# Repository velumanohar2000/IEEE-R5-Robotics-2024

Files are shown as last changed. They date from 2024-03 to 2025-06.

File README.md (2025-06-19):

# Bit Bangers IEEE Region 5 Robotics Competition Robot

This repository contains all resources for the Bit Bangers team's entry in the IEEE Region 5 Robotics Competition.

## Repository Structure

- **Archives/**  
  Contains reference schematics, SolidWorks files, and other archived materials.

- **CAD/**  
  3D models and design files for robot components (STL format).

- **Docs/**  
  Documentation, datasheets, test results, and strategy notes for hardware and software components.

- **Images/**  
  Logos, board images, and other graphics.

- **Software/**  
  All firmware and code for the robot, organized as follows:
  - **Libraries/**  
    Reusable code modules and hardware drivers (e.g., motor controllers, sensors).
  - **Projects/**  
    Main project codebases, such as the robot firmware and remote control.
  - **Testing/**  
    Test programs and experiments for hardware and software validation.

## Getting Started

1. **Hardware**  
   Refer to the CAD and Docs folders for hardware designs and datasheets.

2. **Software**  
   See [Software/README.md](Software/README.md) for details on the code organization.  
   Each project and library may have its own README or documentation.

3. **Building & Running Code**  
   - Navigate to the relevant project or test directory in `Software/`.
   - Follow any provided makefiles or build instructions.

## Authors

Bit Bangers - UTA IEEE Region 5 Robotics Team  
See individual file headers for contributor information.

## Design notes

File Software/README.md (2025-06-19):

- Libraries -> stuff like motor controller libraries with header files
- Testing -> testing libraries for use in the final projects
- Projects -> the actual final projects like the robot or kill switch remote

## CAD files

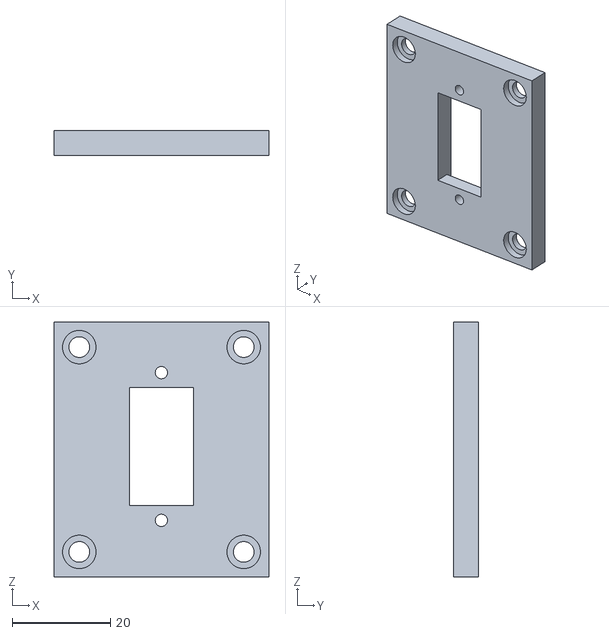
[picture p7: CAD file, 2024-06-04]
CAD/Servo_Platform.stl
43.6 x 5.00 x 51.8

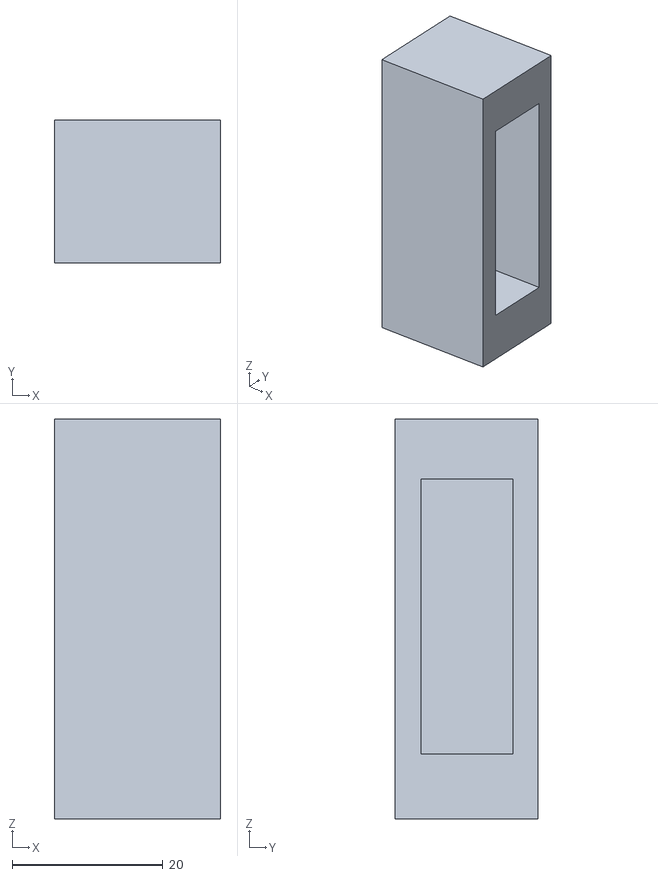
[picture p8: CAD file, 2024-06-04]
CAD/Block.stl
22.0 x 19.0 x 53.0

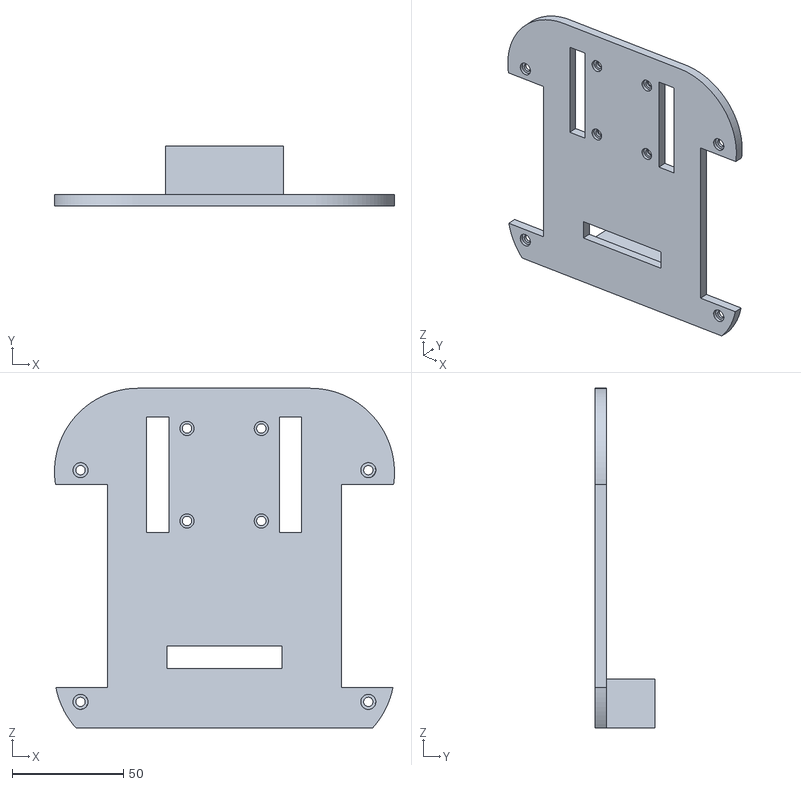
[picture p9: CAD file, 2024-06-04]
CAD/Chassis_Layer_2.stl
152.8 x 26.8 x 152.6

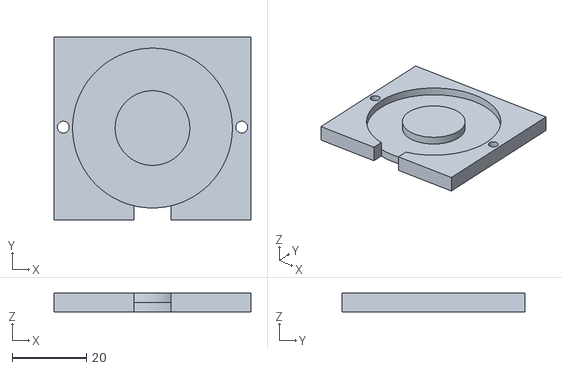
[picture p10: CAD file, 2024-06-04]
CAD/Coil_Slot.stl
53.0 x 49.3 x 5.00

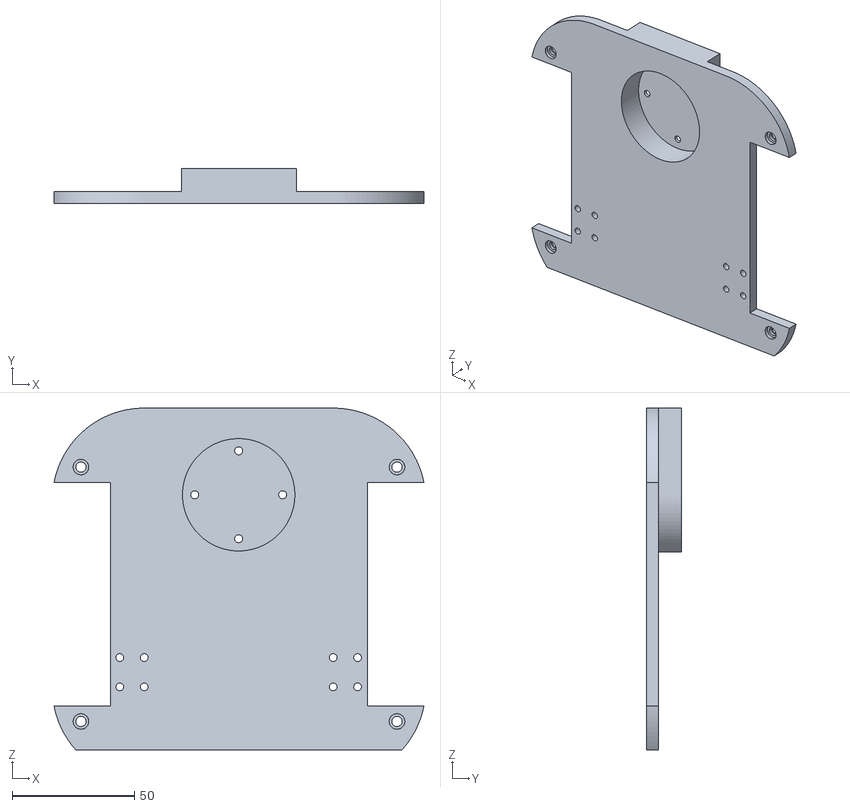
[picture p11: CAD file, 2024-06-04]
CAD/Chassis+w+Swivel+holes.stl
151.5 x 14.5 x 139.9

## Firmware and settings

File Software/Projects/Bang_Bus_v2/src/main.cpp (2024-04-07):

#include <Arduino.h>
#include <Servo.h>
#include <stdbool.h>
#include <Adafruit_BNO08x.h>
#include <Wire.h>
#include <math.h>
#include <ESP32MotorControl.h>
#include <VL53L1X_MULTIPLE.h>
#include "BNO085_heading.h"
#include "motor_control_v2.h",
#include "SparkFun_VL53L1X.h"
#include "IR_switch.h"

// Whisker
uint8_t WHISKER_STOP_DIS = 30;

#define MAX_PRELIM_DIST 60
#define MIN_WALL_DIST_CM 10
#define MAX_WALL_DIST_CM 11

#define TURN_TO_ANGLE_DIFF 2
#define DRIVE_TO_ANGLE_DIFF 20

// Sleep
#define XSHUT_PIN 18

// Variables & Constants ------------------------------------------------------

/*
  Global Variable for the Motors
*/
ESP32MotorControl motors;
// Motors
// Left
const uint8_t MOTOR_A_IN_1 = 6;
const uint8_t MOTOR_A_IN_2 = 7;
int16_t A_LEFT_MOTOR_OFFSET = 15;

// RIGHT MOTOR
const uint8_t MOTOR_B_IN_3 = 5;
const uint8_t MOTOR_B_IN_4 = 4;
int16_t B_RIGHT_MOTOR_OFFSET = 15;

/*
  Global Variable for IMU
*/
Adafruit_BNO08x bno08x;
sh2_SensorValue_t sensorValue;
float offsetForImu = 0;
float goal = 85;

/*
  Globals for (VL53L1X) Whisker
*/
SFEVL53L1X lrf1_init;
SFEVL53L1X lrf2_init;

float frontVLcm = 1000;
float sideVLcm;
// int frontVLcm = 1000;                            // whisker
float frontVLcmInch = 1000; // whisker
int whiskOffset = 0;
bool wallFound = false;

/*
  globals for servo
*/
Servo myservo = Servo();
uint8_t servoPin = 2;
uint16_t servoPosition = 90;

/*
  Globals for IR sensor & sleep
*/
const uint32_t lit_code = 0x574309F6;     // Amazon button
const uint32_t unalive_code = 0x5743D32C; // Netflix button
gpio_num_t ir_pin = GPIO_NUM_11;          // pin number of IR receiver(s)

void setup()
{
  Serial.begin(115200);

  setupBNO085(&bno08x); // Initialize the IMU
  // pinMode(XSHUT_PIN, OUTPUT);
  // digitalWrite(XSHUT_PIN, 0);

  initIR(lit_code, unalive_code);
  while (!wokeFromIR())
  {
    timeToSleep();
  }
  // digitalWrite(XSHUT_PIN, 1);

  delay(1000);

  delay(10);
  Serial.println("*****BANGING THE BUS******\n\n");
  delay(500);

  Wire.begin(9, 8); // init Wire
  init_2_VL53L1X(); // init periscopes

  motors.attachMotors(MOTOR_B_IN_3, MOTOR_B_IN_4, MOTOR_A_IN_1, MOTOR_A_IN_2); // init motors

  uint8_t i = 0;
  offsetForImu = getCurrentAngle();

  Serial.println("offset: ");
  Serial.println(offsetForImu);

  float currentAngle = getCurrentAngle();

  Serial.print("Current Angle: ");
  Serial.println(currentAngle);

  delay(500);

  for (i = 0; i < 50; i++)
  {
    float test = getLrfDistanceCm(1);
    test = getLrfDistanceCm(2);
    Serial.printf("LRF1: %f\n", test);
  }
  myservo.write(servoPin, 90);
  delay(500);
}

void sleepHandler()
{
  stopMotors();
  Wire.end();
  digitalWrite(XSHUT_PIN, 0);
  delay(100);
}

void checkSleep()
{
  if (sleepCodeReceived())
  {
    sleepHandler();
    timeToSleep();
    ESP.restart();
  }
}

// void driveToHeading(float goalHeading)
// {
//   float currentAngle = -1;
//   float absVal;
//   float angleDiff;
//   unsigned long currentMillis;
//   unsigned long previousMillis = 0;
//   uint32_t interval = 1000;
//   uint16_t i = 0;

//   // bool goToHeading = true;
//   // while (goToHeading)
//   // {
//   currentAngle = getCurrentAngle();

//   angleDiff = goalHeading - currentAngle;
//   absVal = abs(angleDiff);
//   uint32_t turnDiff = DRIVE_TO_ANGLE_DIFF;
//   // Serial.println(absVal);
//   if (absVal > (360 - turnDiff))
//   {
//     absVal = 359.99 - absVal;
//     angleDiff = 359.99 - angleDiff;
//   }
//   Serial.println(angleDiff);
//   Serial.println(absVal);
//   Serial.println();

//   if (absVal > turnDiff)
//   {
//     // stopMotors();
//     // delay(20);
//     turnToHeading(goalHeading-10, 60);
//   }
//   else if (absVal <= 15 && absVal >= 5)
//   {
//     if ((angleDiff >= 0) && (absVal <= 180))
//     {
//       turn2(COUNTER_CLOCKWISE, 65, 30);
//     }
//     else if ((angleDiff < 0) && (absVal <= 180))
//     {
//       turn2(CLOCKWISE, 65, 30);
//     }
//     else if ((angleDiff >= 0) && (absVal >= 180))
//     {
//       turn2(CLOCKWISE, 65, 30);
//     }
//     else
//     {
//       turn2(COUNTER_CLOCKWISE, 65, 30);
//     }
//     previousMillis = currentMillis = millis();
//   }
//   else if (absVal < 5 && absVal >= 2)
//   {
//     if ((angleDiff >= 0) && (absVal <= 180))
//     {
//       turn2(COUNTER_CLOCKWISE, 65, 10);
//     }
//     else if ((angleDiff < 0) && (absVal <= 180))
//     {
//       turn2(CLOCKWISE, 65, 10);
//     }
//     else if ((angleDiff >= 0) && (absVal >= 180))
//     {
//       turn2(CLOCKWISE, 65, 10);
//     }
//     else
//     {
//       turn2(COUNTER_CLOCKWISE, 65, 10);
//     }
//   }
//   else
//   {
//     move(FORWARD, 65);
//   }
//   // }
// }

void turnToHeading(float goal, uint8_t speed)
{
  stopMotors();
  // speed = 60;
  printf("Goal: %f\n", goal);
  // delay(3000);
  float absVal;
  float angleDiff;
  uint8_t i = 0;

  float currentAngle = getCurrentAngle();

  // printToLcd("Current Angle: ", currentAngle);
  angleDiff = goal - currentAngle;
  absVal = abs(angleDiff);
  uint32_t turnDiff = TURN_TO_ANGLE_DIFF;
  // Serial.println(absVal);
  if (absVal > 360 - turnDiff)
  {
    absVal = 359.99 - absVal;
    angleDiff = 359.99 - angleDiff;
  }
  // Serial.println(angleDiff);
  // Serial.println(absVal);
  // Serial.println();

  while (absVal > turnDiff)
  {
    checkSleep();
    if ((angleDiff >= 0) && (absVal <= 180))
    {
      // Serial.print(" case 1: ");
      turn(COUNTER_CLOCKWISE, speed);
    }
    else if ((angleDiff < 0) && (absVal <= 180))
    {
      // Serial.print(" case 2: ");
      turn(CLOCKWISE, speed);
    }
    else if ((angleDiff >= 0) && (absVal >= 180))
    {
      // Serial.print(" case 3: ");
      turn(CLOCKWISE, speed);
    }
    else
    {
      // Serial.print(" case 4: ");
      turn(COUNTER_CLOCKWISE, speed);
    }

    currentAngle = getCurrentAngle();

    // Serial.println(goal);
    angleDiff = goal - currentAngle;
    absVal = abs(angleDiff);
    if (absVal > (360 - TURN_TO_ANGLE_DIFF)) // was (absVal > 360 - turnDiff)
    {
      absVal = 359.99 - absVal;
      angleDiff = 359.99 - angleDiff;
    }
    // Serial.println(angleDiff);
    // Serial.println(absVal);
    // Serial.println();
  }
  stopMotors();
}
void driveToHeading(float goalHeading)
{
  float currentAngle = -1;
  float absVal;
  float angleDiff;
  unsigned long currentMillis;
  unsigned long previousMillis = 0;
  uint32_t interval = 1000;
  uint16_t i = 0;

  // bool goToHeading = true;
  // while (goToHeading)
  // {
  currentAngle = getCurrentAngle();

  angleDiff = goalHeading - currentAngle;
  absVal = abs(angleDiff);
  uint32_t turnDiff = DRIVE_TO_ANGLE_DIFF;
  // Serial.println(absVal);
  if (absVal > (360 - turnDiff))
  {
    absVal = 359.99 - absVal;
    angleDiff = 359.99 - angleDiff;
  }
  Serial.println(angleDiff);
  Serial.println(absVal);
  Serial.println();

  if (absVal > turnDiff)
  {
    // stopMotors();
    // delay(20);
    turnToHeading(goalHeading, 60);
  }
  else if (absVal <= 15 && absVal >= 5)
  {
    if ((angleDiff >= 0) && (absVal <= 180))
    {
      turn2(COUNTER_CLOCKWISE, 65, 30);
    }
    else if ((angleDiff < 0) && (absVal <= 180))
    {
      turn2(CLOCKWISE, 65, 30);
    }
    else if ((angleDiff >= 0) && (absVal >= 180))
    {
      turn2(CLOCKWISE, 65, 30);
    }
    else
    {
      turn2(COUNTER_CLOCKWISE, 65, 30);
    }
    previousMillis = currentMillis = millis();
  }
  else if (absVal < 5 && absVal >= 2)
  {
    if ((angleDiff >= 0) && (absVal <= 180))
    {
      turn2(COUNTER_CLOCKWISE, 65, 10);
    }
    else if ((angleDiff < 0) && (absVal <= 180))
    {
      turn2(CLOCKWISE, 65, 10);
    }
    else if ((angleDiff >= 0) && (absVal >= 180))
    {
      turn2(CLOCKWISE, 65, 10);
    }
    else
    {
      turn2(COUNTER_CLOCKWISE, 65, 10);
    }
  }
  else
  {
    move(FORWARD, 65);
  }
  // }
}

// void driveToHeadingVl(float goalHeading)
// {
//   float currentReading = -1;
//   float absVal;
//   float posDiff;
//   unsigned long currentMillis;
//   unsigned long previousMillis = 0;
//   uint32_t interval = 1000;
//   uint16_t i = 0;

//   // bool goToHeading = true;
//   // while (goToHeading)
//   // {
//   currentReading = getLrfDistanceCm(2);

//   posDiff = 13 - currentReading;
//   absVal = abs(posDiff);
//   // uint32_t turnDiff = DRIVE_TO_ANGLE_DIFF;
//   // // Serial.println(absVal);
//   // if (absVal > (360 - turnDiff))
//   // {
//   //   absVal = 359.99 - absVal;
//   //   angleDiff = 359.99 - angleDiff;
//   // }
//   Serial.println(posDiff);
//   Serial.println(absVal);
//   Serial.println();

//   if (absVal > 20)
//   {
//     // stopMotors();
//     // delay(20);
//     turnToHeading(goalHeading, 60);
//   }
//   else if (absVal <= 15 && absVal >= 5)
//   {
//     if ((angleDiff >= 0))
//     {
//       turn2(COUNTER_CLOCKWISE, 65, 30);
//     }
//     else if ((angleDiff < 0) && (absVal <= 180))
//     {
//       turn2(CLOCKWISE, 65, 30);
//     }
//     else if ((angleDiff >= 0) && (absVal >= 180))
//     {
//       turn2(CLOCKWISE, 65, 30);
//     }
//     else
//     {
//       turn2(COUNTER_CLOCKWISE, 65, 30);
//     }
//     previousMillis = currentMillis = millis();
//   }
//   else if (absVal < 5 && absVal >= 2)
//   {
//     if ((angleDiff >= 0) && (absVal <= 180))
//     {
//       turn2(COUNTER_CLOCKWISE, 65, 10);
//     }
//     else if ((angleDiff < 0) && (absVal <= 180))
//     {
//       turn2(CLOCKWISE, 65, 10);
//     }
//     else if ((angleDiff >= 0) && (absVal >= 180))
//     {
//       turn2(CLOCKWISE, 65, 10);
//     }
//     else
//     {
//       turn2(COUNTER_CLOCKWISE, 65, 10);
//     }
//   }
//   else
//   {
//     move(FORWARD, 65);
//   }
//   // }
// }

unsigned long currentMillis = 0;
unsigned long previousMillis = 0;
bool runMillis = 1;
uint32_t interval = 1000;
uint16_t states = 0;

bool firstButton = true;
bool firstRun = true;
#define INITIAL 0
#define RIDE_RIGHT_WALL 1
#define TURN_90_DEG 2
#define TURN_TO_BUTTON 3
#define HIT_BUTTON 4
#define MOVE_BACKWARDS 5
#define TURN_90_DEGREE_AGAIN 6
#define TURN_OTHER_WAY 7
#define STOP 8

void jiggleForRound1()
{
  uint16_t position = 0;
  float currentAngle = getCurrentAngle();
  if (currentAngle >= 0 && currentAngle <= 90)
  {
    position = (90 - currentAngle);
  }
  else if (currentAngle >= 270)
  {
    position = ((360 - currentAngle) + 90);
  }
  else if (currentAngle >= 180 && currentAngle <= 270)
  {
    position = (90 - (currentAngle - 180));
  }
  else if (currentAngle < 180 && currentAngle >= 90)
  {
    position = (180 - currentAngle + 90);
  }
  myservo.write(servoPin, position);
}

uint16_t speed;
unsigned long currentMillisLoop;
unsigned long previousMillisLoop;
;
uint16_t intervalMillisLoop = 7000;

void loop()
{
  checkSleep();
  // if (getLrfDistanceCm(2) >= 25)
  // {
  //   turnToHeading(270, 60);
  //   currentMillis = millis();
  //   previousMillis = millis();
  //   while (currentMillis - previousMillis <= 2000)
  //   {
  //     printf("Current Angle: %f\n", getCurrentAngle());
  //     currentMillis = millis();
  //   }
  //   // turnToHeading(270, 60);

  //   //  delay(3000);
  //   while (getLrfDistanceCm(1) >= 20)
  //   {
  //     driveToHeading(270);
  //   }
  // }

  // stopMotors();
  // delay(2000);
  // turnToHeading(0, 60);
  // stopMotors();
  float check = getLrfDistanceCm(2);
  switch (states)
  {
  case INITIAL:
  {
    Serial.printf("LRF 2: %f\n", check);
    if (check >= 19.0)
    {
      Serial.printf("here\n");
      turnToHeading(270, 70);
      currentMillis = millis();
      previousMillis = millis();
      while (currentMillis - previousMillis <= 2000)
      {
        printf("Current Angle: %f\n", getCurrentAngle());
        currentMillis = millis();
      }
      // turnToHeading(270, 60);

      //  delay(3000);
      while (getLrfDistanceCm(1) >= 15)
      {
        Serial.printf("in the while\n");
        driveToHeading(270);
      }
    }
    stopMotors();
    delay(500);
    turnToHeading(355, 70);
    stopMotors();
    delay(500);
    states = RIDE_RIGHT_WALL;
    break;
  }
  case RIDE_RIGHT_WALL:
  {
    jiggleForRound1();
    currentMillisLoop = millis();
    if (runMillis == 1)
    {
      previousMillisLoop = millis();
      runMillis = 0;
    }
    if (currentMillisLoop - previousMillisLoop >= intervalMillisLoop)
    {
      frontVLcm = getLrfDistanceCm(1);
    }
    else
    {
      frontVLcm = 50;
    }
    //frontVLcm = getLrfDistanceCm(1);
    // frontVLcm = getLrfDistanceCm(1)
    // currentAngle = getHeading();
    if(!firstButton){
      WHISKER_STOP_DIS = 25;
    }
    if (frontVLcm > (WHISKER_STOP_DIS))
    {
      if (frontVLcm > 1200)
        speed = 255;
      else if (frontVLcm > 300)
        speed = 80;
      else
        speed = 50;
      sideVLcm = getLrfDistanceCm(2);

      Serial.printf("ult dist %f: \n", sideVLcm);
      if (sideVLcm > MAX_PRELIM_DIST)
      {
        stopMotors();
      }
      else if (sideVLcm > MAX_WALL_DIST_CM)
      {
        turn(CLOCKWISE, speed);
        delay(40);
        move(FORWARD, speed);
        delay(40);
      }
      else if (sideVLcm < MIN_WALL_DIST_CM)
      {
        turn(COUNTER_CLOCKWISE, speed);
        delay(40);
        move(FORWARD, speed);
        delay(40);
      }
      else
        move(FORWARD, speed);
    }
    else
    {
      stopMotors();
      states = TURN_90_DEG;
      // currentAngle = getHeading();
    }
    break;
  }
  case TURN_90_DEG:
  {
    float angle = 90;
    if (!firstButton)
    {
      turnToHeading(270, 70);
      stopMotors();
      delay(500);
      angle = 270.0;
    }
    else
    {
      turnToHeading(90, 70);
      stopMotors();
      delay(500);
    }
    myservo.write(servoPin, 90);
    if (getLrfDistanceCm(1) > 35)
    {
      while (getLrfDistanceCm(1) < 30)
      {
        driveToHeading(angle);
      }
    }
    states = TURN_TO_BUTTON;
    break;
  }
  case TURN_TO_BUTTON:
  {
    if (!firstButton)
    {
      turnToHeading(180, 70);
      stopMotors();
      delay(500);
    }
    else
    {
      turnToHeading(0, 70);
      stopMotors();
      delay(500);
    }
    states = HIT_BUTTON;
    break;
  }
  case HIT_BUTTON:
  {
    move(FORWARD, 240);
    delay(300);
    stopMotors();
    delay(500);
    states = MOVE_BACKWARDS;
    break;
  }
  case MOVE_BACKWARDS:
  {
    move(BACKWARD, 240);
    delay(500);
    stopMotors();
    delay(500);
    if (!firstButton)
    {
      states = STOP;
    }
    else
    {
      states = TURN_90_DEGREE_AGAIN;
    }
    break;
  }
  case TURN_90_DEGREE_AGAIN:
  {
    turnToHeading(90, 70);
    stopMotors();
    delay(500);
    while (getLrfDistanceCm(1) > 17)
    {
      driveToHeading(90);
    }

    states = TURN_OTHER_WAY;
    break;
  }
  case TURN_OTHER_WAY:
  {
    turnToHeading(180, 70);
    stopMotors();
    delay(500);
    if (firstButton)
    {
      states = RIDE_RIGHT_WALL;
      firstButton = false;
      runMillis = 1;
    }
    else
    {
      states = STOP;
    }
    break;
  }
  case STOP:
  {
    while (1)
    {
      void checkSleep();
      currentMillis = millis();
      jiggleForRound1();
      if (currentMillis - previousMillis >= interval)
      {
        printf("LRF 1 (cm): %f\tLRF 2 (cm): %f\n", getLrfDistanceCm(1), getLrfDistanceCm(2));
        printf("Current Angle: %f\n", getCurrentAngle());
        previousMillis = millis();
      }
    }
  }
  }
  // driveToHeading(0);
}

// int16_t findCardinalheading()
// {
//   float currentAngle = getCurrentAngle();
//   if (currentAngle >= 0 && currentAngle < 45 || currentAngle >= 315)
//   {
//     return 0; // North
//   }
//   else if (currentAngle >= 45 && currentAngle < 135)
//   {
//     return 90; // East
//   }
//   else if (currentAngle >= 135 && currentAngle < 225)
//   {
//     return 180; // South
//   }
//   else if (currentAngle >= 225 && currentAngle < 315)
//   {
//     return 270; // West
//   }
//   else
//   {
//     return -1; // Error
//   }
// }

// void jiggle()
// {
//   float lrf1;
//   float lrf2;
//   float currentHeading = getCurrentAngle();
//   uint16_t cardinalHeading = findCardinalheading();
//   float servoPosition = cardinalHeading - currentHeading; // Calculate the difference between the cardinal heading and the current heading
//   if (abs(servoPosition) > 90)
//   {
//     servoPosition = 359.99 - abs(servoPosition); // 359.99 is the max value for the servo
//   }

//   servoPosition += 90;                    // Add 90 because 90 degress is the middle position for the servo (therefore it is the current heading of the car)
//   myservo.write(servoPin, servoPosition); // tell servo to go to position in variable 'pos'
//   delay(15);                              // waits 15ms for the servo to reach the position
//   lrf1 = getLrfDistanceCm(1);
//   lrf2 = getLrfDistanceCm(2);
//   // Serial.print("LRF1: ");
//   // Serial.print(lrf1);
//   // Serial.print("\tLRF2: ");
//   // Serial.println(lrf2);
//   // findPosition(cardinalHeading, lrf1, lrf2); // Find the position of the car
// }

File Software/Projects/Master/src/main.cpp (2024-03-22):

/*
 * Bit Bangers Master Robot
 * github.com/Bit-Bangers-UTA/Senior-Design
*/

// Libraries ------------------------------------------------------------------

#include "Arduino.h"
#include <stdbool.h>
#include <ESP32Servo.h>
#include "lrf.h"
#include "Wire.h"
#include "map.h"
#include "motor_control.h"
#include "VL53L1X.h"
#include "Ultrasonic.h"
#include <Adafruit_BNO08x.h>
#include "math.h"
#include "BNO085_heading_acceleration.h"
// #include "SafeString.h"
#include "millisDelay.h"

// Defines --------------------------------------------------------------------

// Modes

// Preprocessor Directives
// #define PRELIMS
// #define PRELIMS_DRAFT
// #define PRELIMS_DRAFT_V2
// #define CHECK_I2C
// #define VELU
// #define TURNS
// #define TURNS_2
// #define TURNS_3
#define TURNS_4
// #define INTERRUPTS_CHECK

// Motors
#define MOTORA_IN_1 39
#define MOTORA_IN_2 40
#define MOTORB_IN_3 6
#define MOTORB_IN_4 7

//IMU
#define IMU_INTERRUPT 10

// Whisker
#define WHISKER_STOP_DIS 8
#define MAX_PRELIM_DIST 60

// LRF
#define LRF_ADDRESS_1 0x10
#define LRF_ADDRESS_2 0x20

// Variables & Constants ------------------------------------------------------

/*
counter = 1
++
360 * counter
*/

// Servo
int pos = 0; // variable to store the servo position
// Recommended PWM GPIO pins on the ESP32 include 2,4,12-19,21-23,25-27,32-33
int servoPin = 2;

// Map
// create map and buffer
struct Coordinate *local_maxes[4];
int local_max_index = 0;

// Ultrasonic Sensor
int ultraDistance = 100;         // ultrasonic
float ultraDistanceInch;           // ultrasonic

// Whisker
int whiskDistance;                           // whisker
float whiskDistanceInch = 1000;            // whisker
bool wallFound = false;

// IMU
float test = 45.0;
float nextAngle = 90.0;
uint16_t speed = 128;
// #define TIRE_DELAY 100
// millisDelay tireDelay;
// float angleDiff = 0;
// float startingangle = 0;
uint32_t m = 0;
// Structures & Classes -------------------------------------------------------

// Servo
Servo myservo; // create servo object to control a servo
SFEVL53L1X distanceSensor;
float dt = 0;
float millisOld = 0;
unsigned long lastTime, currentTime = 0;
float x, y, z = 0;
float thetaZ = 0;
// float angle = 0;
uint32_t timeDifference = 0;

// 16 servo objects can be created on the ESP32

// Ultrasonic Sensor
Ultrasonic ultrasonic(0, 1);

// IMU
Adafruit_BNO08x bno08x;
sh2_SensorValue_t sensorValue;

// Functions ------------------------------------------------------------------
// void IRAM_ATTR imuIsr() {
//   // newDataFlag = true;
//   Serial.println("triggered");
//   if (bno08x.getSensorEvent(&sensorValue))
//   {
//     switch (sensorValue.sensorId)
//     {
//       case SH2_GYROSCOPE_CALIBRATED:
//       {
//         z = sensorValue.un.gyroscope.z;
//         break;
//       }
//       default:
//         break;
//     }
//   currentTime = micros();
//   dt = (currentTime - lastTime - 0)/1000000.0;
//   lastTime = currentTime;
//   thetaZ += z*dt;
//   angle = thetaZ*(180/M_PI);
//   if(angle > 360)
//     angle -= 360;
//   else if(angle < 0)
//     angle += 360;
//   }
// }

float getHeading()
{

  float angle = 0;
  float retVal = -1;
  float z = 0;
  if (bno08x.getSensorEvent(&sensorValue))
  {
    retVal = calculateHeading(sensorValue.un.arvrStabilizedRV.i, sensorValue.un.arvrStabilizedRV.j, sensorValue.un.arvrStabilizedRV.k, sensorValue.un.arvrStabilizedRV.real);
  
  // if (bno08x.getSensorEvent(&sensorValue))
  // {
  //   switch (sensorValue.sensorId)
  //   {
  //     case SH2_GYROSCOPE_CALIBRATED:
  //     {
  //       z = sensorValue.un.gyroscope.z;
  //       break;
  //     }
  //     default:
  //       break;
  //   }
  

  // Serial.print(angle);
  // if(angle >= 359)
  //   angle -= 359;
  // else if(angle < 0)
  //   angle += 359;
  // Serial.printf("\t");
  // Serial.println(angle);
  // // if(angle == 0);
  //   // angle = 359;
  // retVal = angle;
  }
  return retVal;

}

void turnToGoalHeading(float goal)
{
  float currentAngle = -1;
  if(goal == 0)
    goal = 359;
  int32_t counter = 0;
  int32_t speed = 100;
  while(currentAngle == -1)
    currentAngle = getHeading();
  float absVal = 0;
  float angleDiff = goal - currentAngle;
  absVal = abs(angleDiff);

  while(absVal > 8)
  {
    Serial.print("abs: ");
    Serial.print(absVal);
    Serial.print(" angle: ");
    Serial.print(currentAngle);

    if((angleDiff >= 0) && (absVal <= 180))
    {
      Serial.print(" case 1: ");
      // Serial.printf("Speed = %f\n", speed + (-1 * counter));
      turn(LEFT, speed);
    }
    else if((angleDiff < 0) && (absVal <= 180))
    {
      Serial.print(" case 2: ");
      // Serial.printf("Speed = %f\n", speed + (-1 * counter));
      turn(RIGHT, speed);
    }
    else if((angleDiff >= 0) && (absVal >= 180))
    {
      Serial.print(" case 3: ");
      // Serial.printf("Speed = %f\n", speed + (-1 * counter));
      turn(RIGHT, speed);
    }
    else
    {
      Serial.print(" case 4: ");
      // Serial.printf("Speed = %f\n", speed + (-1 * counter));
      turn(LEFT, speed);
    }
    counter++;
    if(counter > 12)
      counter = 5;
    currentAngle = getHeading();
    // if(currentAngle > 360)
    //   currentAngle -= 360;
    // if(currentAngle < 0)
    //   currentAngle += 360;
    Serial.println(goal);
    absVal = 0;
    angleDiff = goal - currentAngle;
    absVal = abs(angleDiff);
  }

}

void getWhiskerDistance()
{
  distanceSensor.startRanging(); //Write configuration bytes to initiate measurement
  while (!distanceSensor.checkForDataReady())
  {
    delay(1);
  }
  whiskDistance = distanceSensor.getDistance(); //Get the result of the measurement from the sensor
  distanceSensor.clearInterrupt();
  distanceSensor.stopRanging();
  whiskDistanceInch = whiskDistance * 0.0393701;
  // Serial.printf("Whisker dis (in): %f\n", whiskDistanceInch);
}

void setup()
{
  Serial.begin(115200);
  Wire.begin(9, 8);
  // pinMode(IMU_INTERRUPT, INPUT);
  // attachInterrupt(digitalPinToInterrupt(IMU_INTERRUPT), imuIsr, FALLING);
  Serial.println("Adafruit BNO08x test!");
  // Wire.begin(9, 8);
  initMotors(MOTORA_IN_1, MOTORA_IN_2, MOTORB_IN_3, MOTORB_IN_4);
  initVL53L1X();
  setupBNO085(&bno08x);
  // northEstablished = false;
  #ifdef VELU
  // Serial.begin(115200);
  // Wire.begin(9,8);
  // Allow allocation of all timers
  ESP32PWM::allocateTimer(0);
  ESP32PWM::allocateTimer(1);
  ESP32PWM::allocateTimer(2);
  ESP32PWM::allocateTimer(3);
  myservo.setPeriodHertz(50);          // standard 50 hz servo
  myservo.attach(servoPin, 500, 2400); // attaches the servo on pin 18 to the servo object
                                       // using default min/max of 1000us and 2000us
                                       // different servos may require different min/max settings
                                       // for an accurate 0 to 180 sweep
  #endif
}
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

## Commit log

2024-03-04 Added xbox controller demo. Doesn't work with the ELEGOO smart shield, but should in the future.
    [main.cpp]
2024-03-04 feat:filter bad data
2024-03-07 Added initial code for dummy robot. Currently does not work.
    [main.cpp]
2024-03-07 Fixed bug not allowing car to reverse
    [main.cpp]
2024-03-07 added motor control project
2024-03-07 Added actual variables for forward and reversal, however code still doesn't work. Will be checked later
    [main.cpp]
2024-03-07 Added power pinouts
2024-03-07 not working front lidar code
    [main.cpp]
2024-03-07 added vl53- i2c project
2024-03-07 Remove unused function and initialize VL53L4CX sensor
2024-03-08 Added functions and addresses for i2c operation. We might be cooked, they have no documentation for user operation. We may need to use their library
2024-03-11 Added both kill switch receiver and transmitter projects
2024-03-11 Fixed formatting of various files
    [main.cpp]
2024-03-11 peak detection and imu testing
2024-03-11 add half speed ifdef for motor_control
2024-03-13 Add board_build.f_cpu and preprocessor directives, fix turning function
    [main.cpp]
2024-03-13 Added controlled capacitor testing project
2024-03-16 added test code for sevo + whiskers (not working)
    [main.cpp]
2024-03-16 mainly added comments + new code in motor control to turn with angle
2024-03-16 Change stop() with vlk from digital to pwm version
2024-03-16 Re-write motor_control to use PWM, change stop() function in main
2024-03-16 Organize map.cpp, add max distance for ultrasonic sensor
2024-03-16 Update ultrasonic sensor variable names and logic
2024-03-17 Detecting loaction with servo, it can either detect with two peaks or 1 max and 1 peak.
2024-03-17 noted some ideas on how to fix tthe diagonal location problem
    [main.cpp]
2024-03-18 removd duplicate serial and wire inits
2024-03-18 corrected draft code for first round with imu angles
    [main.cpp]
2024-03-19 bunch of broken code in master
    [main.cpp]
2024-03-20 slightyly better but still very broken master code
    [main.cpp]
2024-03-20 improved filtering for 180 degree servo
2024-03-22 included inis for s3, still broken code
    [MOTOR_CONTROL.cpp, main.cpp]
2024-03-22 made minor changes to motor control library
2024-03-22 Add RGB LED sensor project (not working)
    [main.cpp]
2024-03-22 changed the 2nd i2c bus
2024-03-22 color sensor work/ rgb no worl
2024-03-23 Revert i2c change
2024-03-23 Remove Wire1 code, change motor numbers and variable names, add ultrasonic defines
2024-03-24 Added test wee-woo program that shows usage of the RGB LED and testing upload, debug, and monitor of code with the esp-prog
2024-03-24 move Dummy_Robot, Master-Old, and old esp-now switch from /Projects to /Testing folder
2024-03-24 Move IR Kill Switch transmitter project from /Testing to /Projects
2024-03-24 Added RGB output to builtin RGB LED of c3. Needs additional filtering
2024-03-24 Adjusted BNO heading library and changed Bang Bus pins for motors
2024-03-24 motor calibration and code to drive to desired heading
2024-03-24 Add motor_control_v2 to /Libraries
2024-03-25 print to lcd
2024-03-25 added sample code for VL53L5CX
2024-03-25 initial libraries for calibration
2024-03-25 moved initial calibration code to libraries folder
2024-03-28 Added prelim code testing with OPT Whisker sensor
2024-03-30 Fixed getNextAngle(), moved code from libs back to main, edited motor offsets
    [main.cpp]
2024-03-30 changed name of IMU library because we are not getting the acceleration anymore, and moved the IMU to Wire1
2024-04-01 Added some starter code for deep sleep, but doesn't work for C3. C3 does not have EXT0 wakeup
    [main.cpp]
2024-04-01 Added deep sleep test for the ESP32-S3
2024-04-02 added code for testing just motors
2024-04-02 Add alternating direction for motor movement
2024-04-02 Update motor pin assignments
2024-04-02 add sensor color pages
2024-04-03 Fix pin assignments for LRF shutdown pins
2024-04-03 Update color detection to print colors to serial
2024-04-03 Update print statement in main.cpp
2024-04-03 Turned color detection into library, added small library test for sensor
2024-04-03 fixed stoppin issue unable to fix the smooth travel issue
    [main.cpp]
2024-04-03 changed the name for the sensor
2024-04-03 Add new libraries (ESP32Servo and ESP32S2 AnalogWrite) to bangbus
2024-04-03 Update motor control offsets
2024-04-03 Fix motor stop bug in turn function
2024-04-03 Update whisker and wall distance constants (broken ass code)
    [main.cpp]
2024-04-03 Fix IR sleep integration code. It now works pog
    [main.cpp]
2024-04-03 Tune color sensor
2024-04-04 Added IR Switch Library
2024-04-04 Update IR receiver pin and fix wake condition
    [main.cpp]
2024-04-04 Fix IR switch code and update platformio.ini
2024-04-04 Remove unnecessary code and add missing newline at end of file
    [main.cpp]
2024-04-04 Comment out printing preprocessor directive
2024-04-04 working color sensor logic
2024-04-04 Removed unnecessary prints, updated codes for buttons
2024-04-05 color sensor logic
2024-04-05 fixed light sensor library
    [main.cpp]
2024-04-06 Update Whisker stop distance and add new states for button interaction
2024-04-06 Update IR pin
2024-04-06 Add ambient color sensor project
2024-04-06 IR testing, not working yet
    [main.cpp]
2024-04-06 Fix BNO not initializing
    [main.cpp]
2024-04-06 fixed BNO085 and tcs color sensor library
    [main.cpp]
2024-04-06 fea: fix undefined vars
    [main.cpp]
2024-04-06 color sensor integration
2024-04-06 color sensor not working
    [main.cpp]
2024-04-06 retesting imu
2024-04-07 Moved lidar testing results to Docs
2024-04-25 demo day branch and psedo code
    [BB_PCB_A.kicad_pcb, BB_PCB_A.kicad_sch]
2024-06-04 Add CAD files
    [Block.stl, Chassis+w+Swivel+holes.stl, Chassis_Layer_2.stl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]
